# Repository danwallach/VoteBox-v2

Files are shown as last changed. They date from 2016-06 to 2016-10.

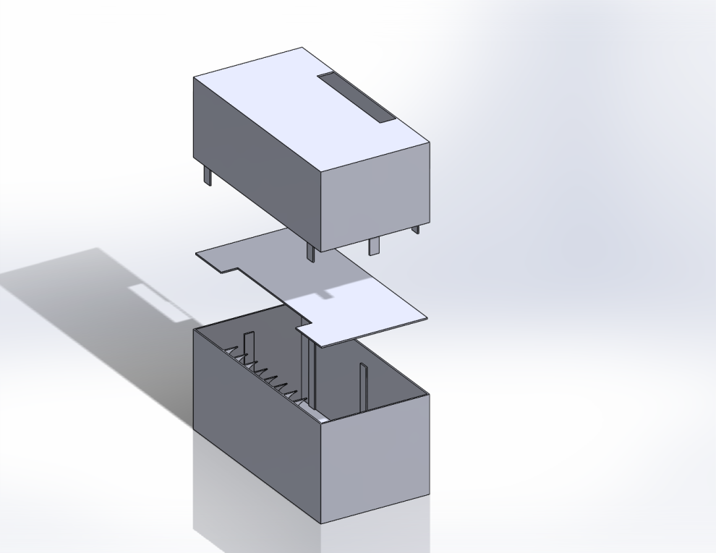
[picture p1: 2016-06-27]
box-schematics/box-render.png

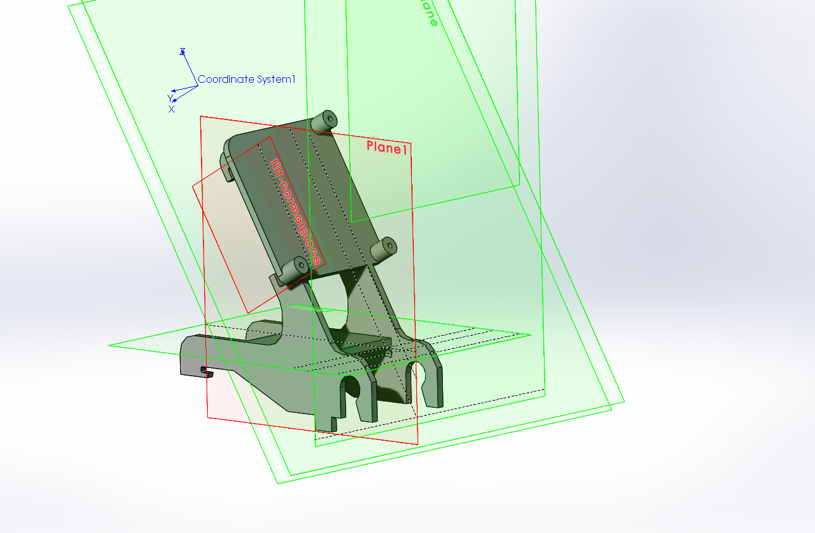
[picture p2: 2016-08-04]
box-schematics/holderbase.PNG

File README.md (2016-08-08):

# VoteBox version 2

An improved version of the original [Vote Box](https://github.com/danwallach/VoteBox-v1) created for the STAR-Vote project.

## Directories
*   `box-schematics` CAD schematics of mechanical components
*   `circuitdiagram` Electronic circuit diagrams
*	`java` Java ballotbox software implementation
*   `scan-src` Source files for barcode scanner module
*   `servo-src` Source files for hardware PWM servo module (experimental)

## Files
### Core Programs
*   `votebox.py` Main routine
*   `status_server.py` Ballot box status server for use with web frontend
*   `take_in.py` Paper intake and sorting routine
*   `diverter.py` Diverter control library
*   `rpi_servodriver.py` Servomotor control library
*   `scan` Barcode scanner program

### Configuration Files
*   `config.py` Config options for main program
*   `diverter_config.py` Config options for diverter controller

### Testing Programs
*   `servotest.py` Servomotor library test program
*   `servotest_interactive.py` Interactive servo test program

### Documentation
*   `network-notes.md` Documentation of Epson DS-510 driver hacking
*   `scanner-codes.md` Documentation of Epson ESCI/2 scanner communication protocol

### Miscellaneous
*   `ping_slack` Script that sends device IP to Slack chat

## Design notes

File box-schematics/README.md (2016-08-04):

# Solidworks schematics

## Barcode scanner mount
3D printed part that attaches the barcode scanner to the printer frame.

* `holderbase.sldprt` Solidworks part file.
* `holderbase.slddrw` Solidworks part drawing.
* `holderbase.stl` For 3D printer.

## Ballot box enclosure
Mockup of ballot box enclosure.

* `ballotbox-assy.sldasm` Solidworks file of assembled box.
* `ballotbox-bottompart.sldprt` Solidworks part file for base of box.
* `ballotbox-platepart.sldprt` Solidworks part file for printer support plate.
* `ballotbox-toppart.sldprt` Solidworks part file for top of box.
* `ballotbox-assy.pdf` Part drawing of assembled ballot box.
* `box-render.png` Render of assembled ballot box.

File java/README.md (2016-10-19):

# Ballot box driver, Java edition 1.9

Driver application for the STAR-Vote ballot box, written in Java for the Raspberry Pi.

## Requirements
- Raspberry Pi 3
- Java 1.8
- [WiringPi](http://wiringpi.com/)
- [Pi-blaster](https://github.com/sarfata/pi-blaster)

### Note on pi-blaster
Pi-blaster **must** be daemonized and configured with a pulse frequency of 50 Hz before
running this application (refer to its documentation to see how to do this). We have
also noted broken PWM behavior if the daemon is started immediately at boot. This was
resolved by delaying the start of pi-blaster by 30 seconds on boot.

*Update 9/28/2016*: The cause of the unreliable PWM behavior may be due to dynamic
PWM clock scaling specific to certain conditions on the Pi3 (possibly HDMI). To
resolve, run pi-blaster in PCM mode:

`./pi-blaster --pcm`

### Root access
The application may be run with normal privileges if the machine is running Raspbian
with Linux kernel version 4.1.7 or newer. Otherwise, the application must be run as
root to allow hardware GPIO access.

## Run
Run `./gradlew run. This should only be used for development testing.

## Install
To build the application locally:

`./gradlew installApp`

This will package the application and all dependencies into JARs and place
them in the directory `build/install/ballotbox`. Three variants of the
application are installed:

* `bin/ballotbox`: Networked to the STAR-Vote protocol and displays status
messages via a web-based UI. The UI itself must be downloaded and hosted
separately (see Votebox-Display).
* `bin/ballotboxsw`: Non-networked and displays status messages via Swing.
* `bin/ballotboxfx`: **Experimental.** Displays status messages via JavaFX.
Note that JavaFX is not included in the ARM JDK distribution, so this cannot
actually be run on the RPi.

**Important**: from the command line, the application must be started with
the working directory at the installation root. This is currently necessary
due to design flaws in legacy STAR-Vote code. For example, to start
`ballotboxsw`, use

~~~
cd build/install/ballotbox
bin/ballotboxsw
~~~

### Running from remote session
If running the Swing-based variant over SSH, the X11 display must be set to
the host's physical display. This can be done by setting the `DISPLAY`
environment variable:

`export DISPLAY=:0.0`

## Deploy
To package the application in a self-contained archive package:

`./gradlew distTar`

The resulting tar package is placed in `build/distributions`. This is the equivalent of
packaging the output of _Install_ in a tar archive.

## Documentation
Generate documentation by running

`./gradlew javadoc`

The resulting JavaDoc is placed under `build/docs`. Source code for this
project is formatted with Markdown and converted to JavaDoc HTML with the
[pegdown-doclet](https://github.com/Abnaxos/pegdown-doclet) plugin, which is
included in the provided Gradle configuration. The IntelliJ IDEA [Pegdown
Doclet plugin](https://plugins.jetbrains.com/plugin/7253?pr=idea) may be
optionally installed to properly render Markdown comments in the Quick
Documentation viewer.

## Source
This software was developed in IntelliJ IDEA and built with Gradle. Opening
this directory (`/java`) as project root in IntelliJ should import everything
in a working state. You may need to manually refresh Gradle for it to download
the necessary dependencies.

The Gradle task `application/run` can be used to run the program as configured
in Gradle. To run it through IntelliJ or manually, the main entry point is via
`edu.rice.starvote.Controller.main()`.

## Known Issues
* During operation, a `ConcurrentModificationException` is sometimes thrown.
This does not appear to interfere with any functionality. It is likely a bug
introduced in version 1.1 of the Pi4J library.

## Todo
- Debugging

## Authors
- luejerry

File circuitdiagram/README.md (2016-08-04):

# Ballot box electrical schema

## Folders
* `datasheets` Manufacturer datasheets for electronic components
* `PCB` Files for PCB fabrication
* `PCB-1.02` Files for PCB fabrication with onboard sound driver (has issues with interference noise, not suitable for use)

## Files 
* `rpi-ballotbox.fzz` [Fritzing](http://fritzing.org) circuit diagram file

### Circuit diagram
* `rpi-ballotbox_schem.svg` Render of circuit schematic
* `rpi-ballotbox_schem.png` Render of circuit schematic
* `rpi-ballotbox_schem.pdf` Render of circuit schematic

### Breadboard diagram
* `rpi-ballotbox_bb.png` Render of breadboard schematic
* `rpi-ballotbox_bb.svn` Render of breadboard schematic

### PCB diagram
* `rpi-ballotbox_pcb.pdf` Render of PCB schematic

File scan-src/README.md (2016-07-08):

# scan: barcode scanner program

## Compiling
Run `make`. The WiringPi library must be installed.

## Usage
Before running, ensure the barcode scanner is activated by HIGH signal on BCM
pin 25. Run `scan` as root.

* `sudo ./scan` Scan until valid code is read.
* `sudo ./scan 5` Scan until code read or 5 seconds have elapsed.

On successful code read, the program prints the code followed by a newline to
`stdout` and exits. Nothing is printed if no code is read.

## Notes
Only printable ASCII characters and the space character are supported. Should
be good for Code 128 and below.

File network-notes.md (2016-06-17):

# Compiling Epson scanner binaries for ARM

Epson does not provide precompiled ARM Linux driver binaries for the DS-510 scanner. It does, however, provide sources
available [here](http://support.epson.net/linux/src/scanner/imagescanv3/debian/imagescan_3.16.0.orig.tar.gz). We must
compile it ourselves to use the manufacturer drivers on the RPi.

## Compile epson imagescan (utsushi) drivers on the RPi

1. download and extract source tar:
    ```
    curl -LOC http://support.epson.net/linux/src/scanner/imagescanv3/debian/imagescan_3.16.0.orig.tar.gz
    tar -zxf imagescan_3.16.0.orig.tar.gz
    ```
    
2. install `libboost-dev-all`
3. run configure script, specifying boost library location (`/usr/lib/arm-linux-gnueabihf`)

    `./configure --with-boost-libdir=/usr/lib/arm-linux-gnueabihf`

4. `make`

This step failed with compiler error due to insufficient memory. Error persisted even after increasing swap space
to 8 GB. Cross compiling on a more powerful system appears to be necessary here.

## Cross-compiling utsushi drivers from amd64 Ubuntu 16.04 machine, take one

On target machine (rpi):

1. download boost c++ libraries

    `sudo apt-get install libboost-all-dev`

2. archive the installed binaries and transfer to build machine

    `tar -zcf lib.tar.gz /usr/lib/arm-linux-gnueabihf`

On build machine (amd64-ubuntu):

1. download and extract driver source as above
2. download c++ boost libraries

    `sudo apt-get install libboost-all-dev`

3. extract target boost binaries

    `tar -zxf lib.tar.gz`

4. download RPi cross compiling toolchain off github

    `git clone https://github.com/raspberrypi/tools`

5. add toolchain binaries for build system to PATH in ~/.bashrc

    `export PATH=$PATH:~/tools/arm-bcm2708/gcc-linaro-arm-linux-gnueabihf-raspbian-x64/bin`

6. run configure script, specifying target boost library location and cross-compile host

    `./configure --with-boost-libdir=./lib/arm-linux-gnueabihf --build=x86_64-linux-gnu --host=arm-linux-gnueabihf`

7. `make`

8. archive the directory and transfer to target machine

On target machine:

1. reconfigure to target

    `./configure --with-boost-libdir=/usr/lib/arm-linux-gnueabihf`

2. `make check`

   * This step failed with binaries in utsushi/connexions/.lib failing tests. Easy solution is to just recompile these
natively, since these are not a problem for the pi
    ```
    cd connexions
    make
    ```

   * Rerun `make check` in project root 

   * Now errors are generated due to missing dependencies used by the testsuite. Install them

    `apt-get install tesseract-ocr graphicsmagick doxygen graphviz`

   * The Makefile in `./filters/tests` needs to be updated to point to graphicsmagick. Do not rerun configure; it will
force a recompile. Change the `CONVERT=` to

    `CONVERT=gm convert`

   * Rerun `make check`

At this point, it became evident that make had used the built-in gcc rather than the cross-compiler, possibly due to
autodetection of x86\_64 libraries. I decided to abandon the cross-compiling approach and go with full environment
emulation instead, since the road of cross-compiling the entire dependency tree leads only to horrors beyond mortal
comprehension.

## Compiling utsushi drivers with ScratchBox2 and qEmu

Fortunately, another brave soul had set up a VM for emulated compilation with ScratchBox2 and qEmu and posted it to
[Github](https://github.com/nickhutchinson/raspberry-devbox). Unfortunately, it was quite outdated, using the previous
distribution of Raspbian (Wheezy) and an old cross compilation toolchain. Trying to compile the drivers in emulation
mode was met with many errors and warnings of deprecated assembly output (?!). After an afternoon of modifications to
the VM provisioning scripts, I was able to generate a VM using the current Raspbian Jessie distribution and cross
compilation toolchain, which I have placed in [this Github repository](https://github.com/luejerry/raspberry-devbox).

The emulated compilation approach uses ScratchBox2 and qEmu to emulate a Raspbian chroot, itself inside an Ubuntu 12
VM running in Vagrant/Virtualbox on the host system. Fully emulated compilation is extremely slow, a small price to
pay for one's sanity.

On host machine (amd64 ubuntu):

1. Get the scratchbox2/qemu RPi VM box

    `git clone https://github.com/luejerry/raspberry-devbox`

2. Set it up using the instructions in README
    ```
    vagrant up
    vagrant ssh
    ```

3. At this stage, a problem with mismatching locales was encountered ("could not set locale"). To fix, generate locales
for all en\_US languages

    `sb2 -eR dpkg-reconfigure locales`

   * Select (spacebar) all locales starting with `en_US`
   * Choose `en_US` as default locale

4. Download and extract driver source as above
5. Download boost libraries to the chroot

    `sb2 -eR apt-get install libboost-all-dev`

6. Run configure in emulation mode, specifying a staging directory

    `sb2 -e ./configure --with-boost-libdir=/usr/lib/arm-linux-gnueabihf --prefix=$HOME/deploy`

7. Run make in emulation mode (takes a long time)

    `sb2 -e make`

8. Run make check in emulation mode

    `sb2 -e make check`

   * Could not get past this point on the host machine due to test programs segfaulting when running under qEmu. Since
the hard part has been built, we can copy the build products to the Pi and run the test there, being careful not to
trigger a recompile

9. Archive the utsushi folder and send to Pi

On target machine (arm rpi):

1. Extract the utsushi folder to the same absolute path as on host, or symlink to it

    `sudo ln -s /home/pi /home/vagrant`

2. Install the necessary dependencies in `install-deps.sh` (we installed by hand to avoid installing unnecessary automake
tools)

    `sudo ./install-deps.sh`

3. `make check`

4. `sudo make install`

   * This will install to the prefix folder specified when configure was ran, in this case `~/deploy`. A driver file is
also installed to `/etc/udev/rules.d`.

# Compiling SANE binaries for ARM

[SANE](www.sane-project.org) introduced partial support for the DS-510 in version 1.0.25 with the introduction of the
`epsonds` module. Although the SANE frontend can be used with Utsushi, the backend driver is completely independent and
gives us an alternative option for using the scanner on the Pi.

## Precompiled binaries

The latest precompiled SANE packages on the Raspbian Jessie repository are version 1.0.24, which is outdated and does not
support the DS-510. We tried installing the latest stable release (1.0.25) from the experimental Debian Stretch repository,
but encountered a known bug in which the scanner would only accept one command successfully before failing with an IO error.
Others had reported this bug fixed in the latest unstable snapshots, which are only available as source and thus have to be
compiled. Fortunately, the RPi 3 is more than capable of compiling the necessary modules natively without the need for any
cross compilation insanity.

## Compiling on RPi

### Compiling backend driver

The backend driver module `epsonds` must be compiled and installed before the frontend is installed.

1. Download the SANE development sources from Github.

    `git clone git://git.debian.org/sane/sane-backends.git`

   - We received `sane-backends` on commit `e7100e275d58d67b903e883e7a02e45d18f81ef7`.

2. Make sure `libusb-dev` is installed.

3. Run configure in `sane-backends`, specifying that only to compile the driver module we need

    `./configure BACKENDS="epsonds"`

4. `make`

5. `sudo make install`

### Compiling frontend driver

1. Download the SANE development sources from Github.

    `git clone git://git.debian.org/sane/sane-frontends.git`

2. `./configure`

3. `make`

4. `make install`

5. Add `/usr/local/lib` to the library search path by adding it to `ld.so.conf` and running `ldconfig` as root. Alternatively,
set the environment variable `LD_LIBRARY_PATH=/usr/local/lib` in execution

    `LD_LIBRARY_PATH=/usr/local/lib scanimage -L`

# Useful tricks

- To see exactly which libraries are being loaded (and which ones are failing to load), set the environment variable `LD_DEBUG`:
    ```
    export LD_DEBUG=files	# displays library files
    export LD_DEBUG=bindings	# displays symbol bindings
    export LD_DEBUG=libs	# displays lib search paths
    export LD_DEBUG=help	# displays other possible options
    ```

- To write both stdout and stderr to a file while still printing to the console, use

    `<command> 2>&1 | tee <outfile>`

# Temporary notes

- _Make sure `pkg-config` is installed in the RPi chroot!_ It comes installed on the normal Raspbian distro but not when
using `debootstrap`. Epson driver `configure` will silently fail to detect `libudev` and `libusb` if this is not installed!

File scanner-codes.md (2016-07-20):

# Scanner code documentation
Scanner request/responses are encoded in 64-byte string tokens beginning with a
four character code. All available codes are provided in the `utsushi` source
file `utsushi/drivers/esci/code-token.hpp` but their meaning appears to be
undocumented. This is a list of tokens with their inferred meanings from
examining the source code.

Tokens are grouped into namespaces (sections) in the source according to their
general function. The grouping has been preserved here.

## Request tokens

| Token | Definition |
| ----- | --- |
| FIN | Finished with device |
| CAN | Cancel command |
| INFO  | Get scanner information |
| CAPA  | Get scanner capabilities |
| CAPB  | Get scanner capabilities, flip side only |
| PARA  | Get/set parameters |
| PARB  | Get/set parameters, flip side only |
| RESA  | Get/set resolution |
| RESB  | Get/set resolution, flip side only |
| STAT  | Get scanner status |
| MECH  | Send mechanical command (below) |
| TRDT  | Initiate scan, transition to data state (below) |
| IMG | Acquire scanned image data |
| EXT0  | Transfer blobs |
| EXT1  | Transfer blobs |
| EXT2  | Transfer blobs |

## Response tokens

### Request Error
All responses are headed by the original request code received, unless an error
occurs: a `UNKN` response indicates an unknown request code, and `INVD`
indicates that a known request was received at an invalid time.

### Info

#### Types
Each token here may be followed by additional tokens specific to its type,
defined in another section below. 

| Token | Definition |
| ----- | --- |
| #ERR  | Hardware error |
| #NRD  | Not ready |
| #PST  | Page start, sent after first IMG request for an image |
| #PEN  | Page end, sent after image completes scanning |
| #LFT  | Images left to scan, if number of pages was specified using PAG |
| #TYP  | Side of page being scanned |
| #ATN  | Device attention |
| #PAR  | Scan parameter notification, in response to PARA, PARB, RESA, OR RESB request |
| #END  | End of response, is not necessarily present |

#### ERR tokens
Hardware location of error:

| Token | Definition |
| ----- | --- |
| ADF | Automatic document feeder |
| TPU | Transparency unit |
| FB | Flatbed |

Nature of error:

| Token | Definition |
| ----- | --- |
| OPN | |
| PJ | Paper jam |
| PE | |
| ERR | Generic error |
| LOCK  | |
| DFED  | |
| DTCL  | |
| AUTH  | |
| PERM  | |
| BTLO  | |

#### NRD tokens

| Token | Definition |
| ----- | --- |
| RSVD  | |
| BUSY  | Device busy |
| WUP | |
| NONE  | |

#### TYP tokens

| Token | Definition |
| ----- | --- |
| IMGA  | Front side |
| IMGB  | Back side |

#### ATN tokens

| Token | Definition |
| ----- | --- |
| CAN | |
| NONE  | |

#### PAR tokens

| Token | Definition |
| ----- | --- |
| OK | Parameters set successfully |
| FAIL  | Failed to set parameters |
| LOST  | |

## Value tokens

| Token | Definition |
| ----- | --- |
| LIST  | List of integers or tokens |
| RANG  | Range defined by two integers |

## Capability tokens
Todo

## Parameter tokens
Truncated

| Token | Definition |
| ----- | --- |
| #PAG  | Number of images to scan. Each duplex scan counts as two images |

## Mechanical tokens
Type of mechanical action:

| Token | Definition |
| ----- | --- |
| #ADF  | Automatic document feeder |
| #FCS  | Focus control |
| #INI  | |

ADF actions:

| Token | Definition |
| ----- | --- |
| LOAD  | Load sheet |
| EJCT  | Eject sheet |
| CLEN  | Clean |
| CALB  | Calibrate |

FCS actions:

| Token | Definition |
| ----- | --- |
| AUTO  | Autofocus |
| MANU  | Manual focus |

## Transition (TRDT)
The `TRDT` request initiates the scan, putting the scanner in "data state."
Only `FIN`, `CAN`, `IMG` and `EXT` requests can be sent in this state. The
scanner exits this state when images have been acquired, it receives a `FIN`
or `CAN` request, or an error occurs. When not in this state, `CAN` and `IMG`
requests are considered invalid.

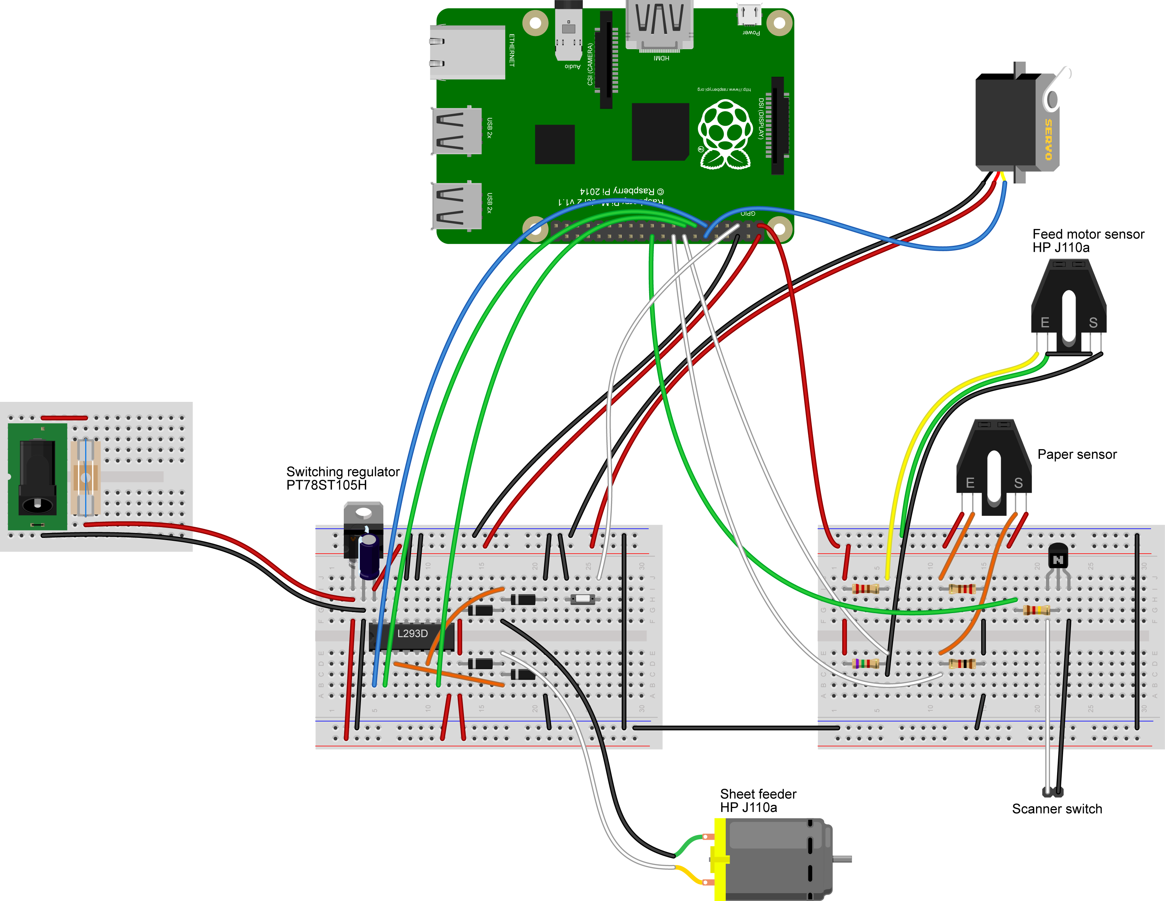
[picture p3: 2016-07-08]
circuitdiagram/rpi-ballotbox_bb.png

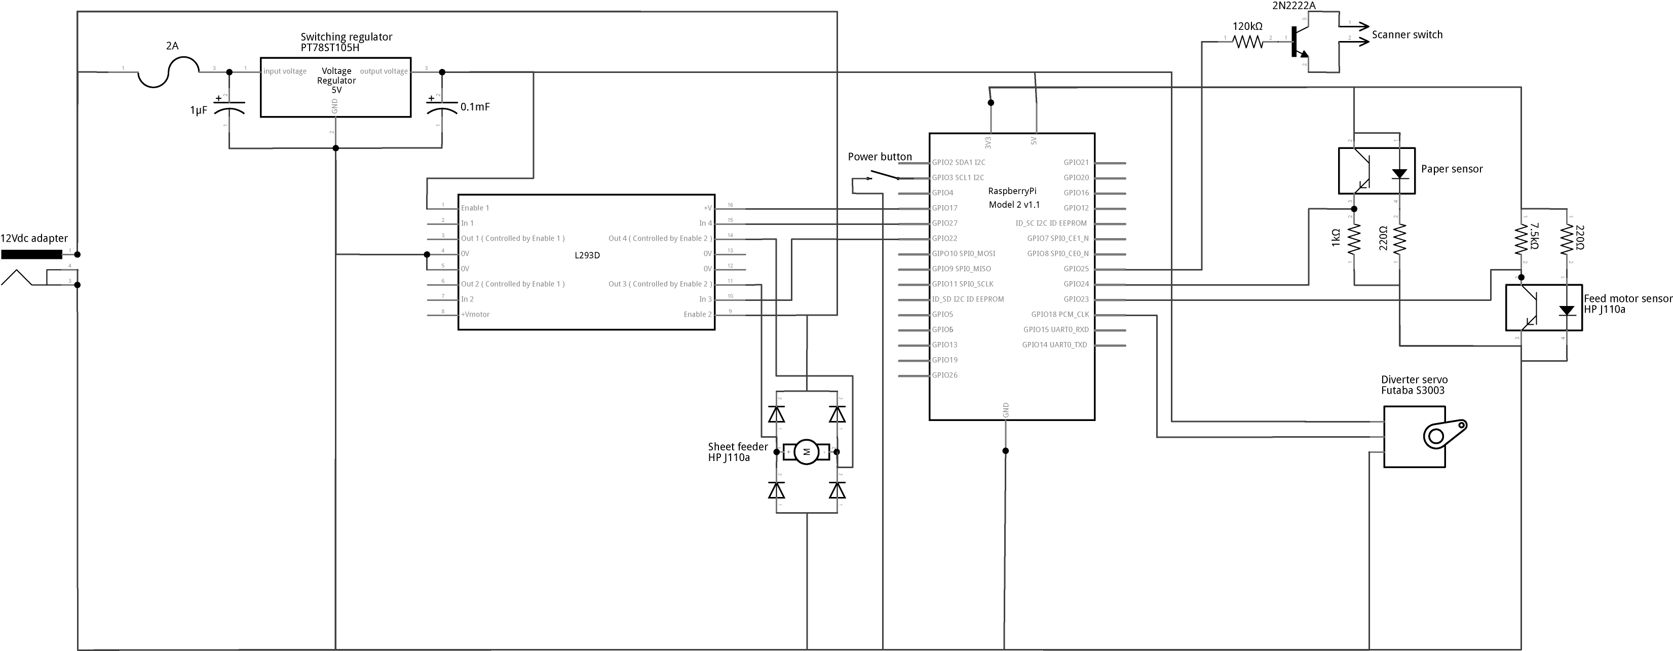
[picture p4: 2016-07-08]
circuitdiagram/rpi-ballotbox_schem.png

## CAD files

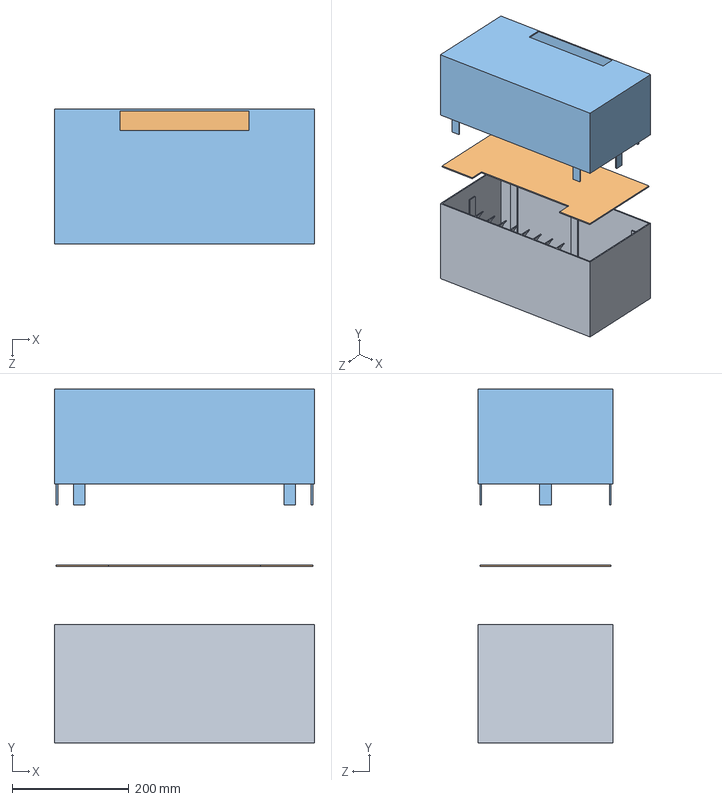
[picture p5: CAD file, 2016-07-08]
box-schematics/ballotbox-assy.SLDASM
446.0 x 606.3 x 231.0 mm
ballotbox-bottompart
ballotbox-platepart
ballotbox-toppart

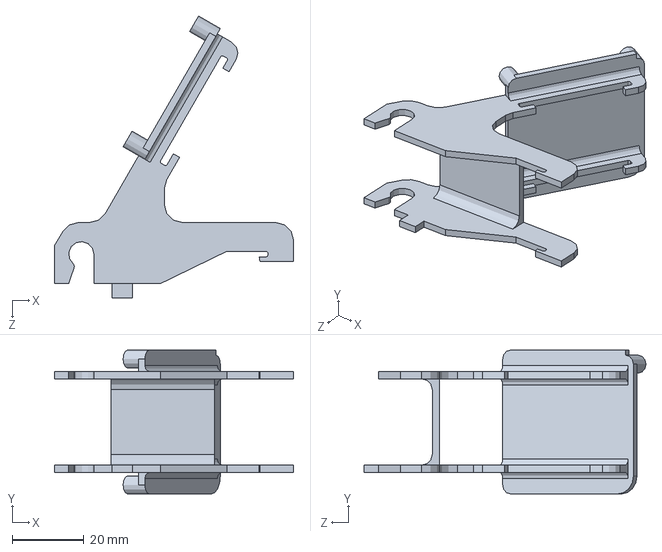
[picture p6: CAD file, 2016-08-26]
box-schematics/holderbase.SLDPRT
66.6 x 40.0 x 78.5 mm

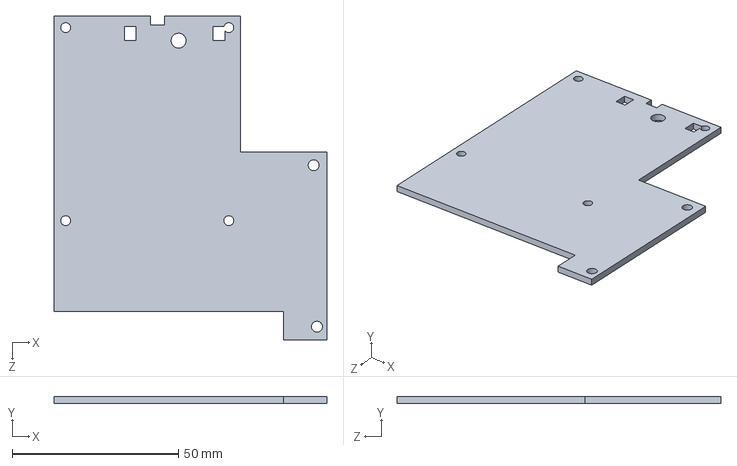
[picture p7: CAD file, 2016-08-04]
circuitdiagram/rpimount.SLDPRT
82.0 x 2.10 x 97.3 mm

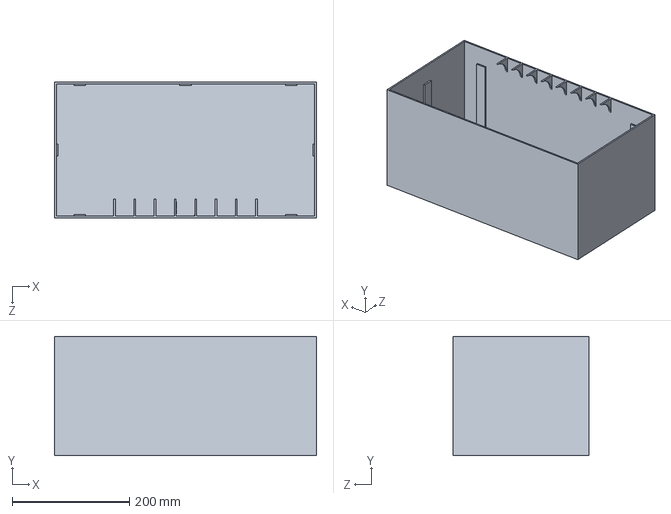
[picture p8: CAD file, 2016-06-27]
box-schematics/ballotbox-bottompart.sldprt
446.0 x 203.0 x 231.0 mm

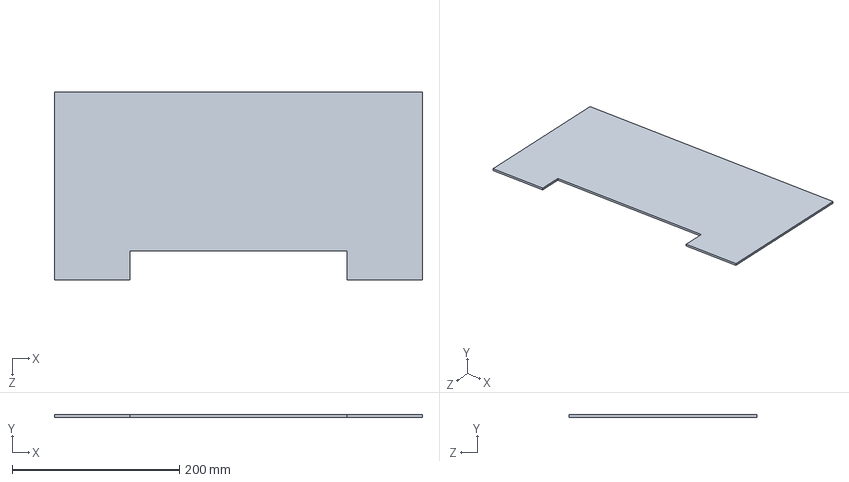
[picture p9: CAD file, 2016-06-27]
box-schematics/ballotbox-platepart.sldprt
440.0 x 3.00 x 225.0 mm

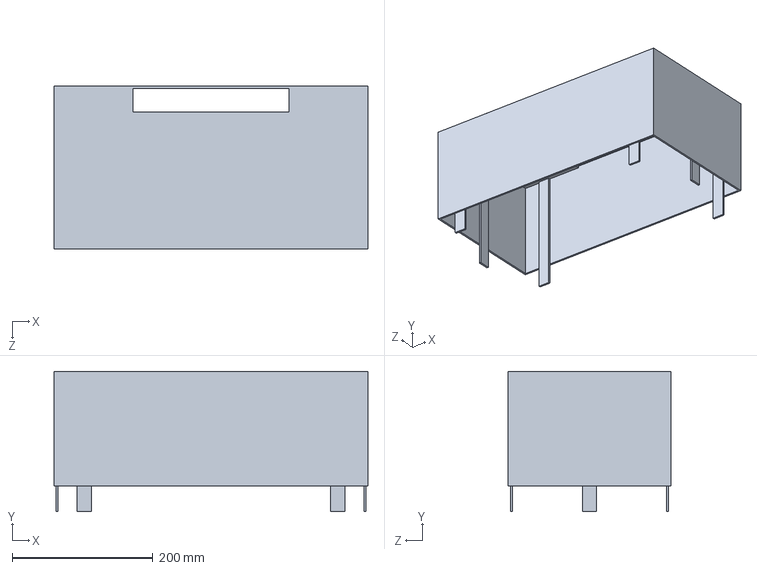
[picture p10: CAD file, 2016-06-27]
box-schematics/ballotbox-toppart.sldprt
446.0 x 199.0 x 231.0 mm

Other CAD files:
box-schematics/ballotbox-assy.SLDDRW
box-schematics/holderbase.SLDDRW
box-schematics/holderbase.STL
circuitdiagram/rpimount.DXF
circuitdiagram/rpimount.SLDDRW

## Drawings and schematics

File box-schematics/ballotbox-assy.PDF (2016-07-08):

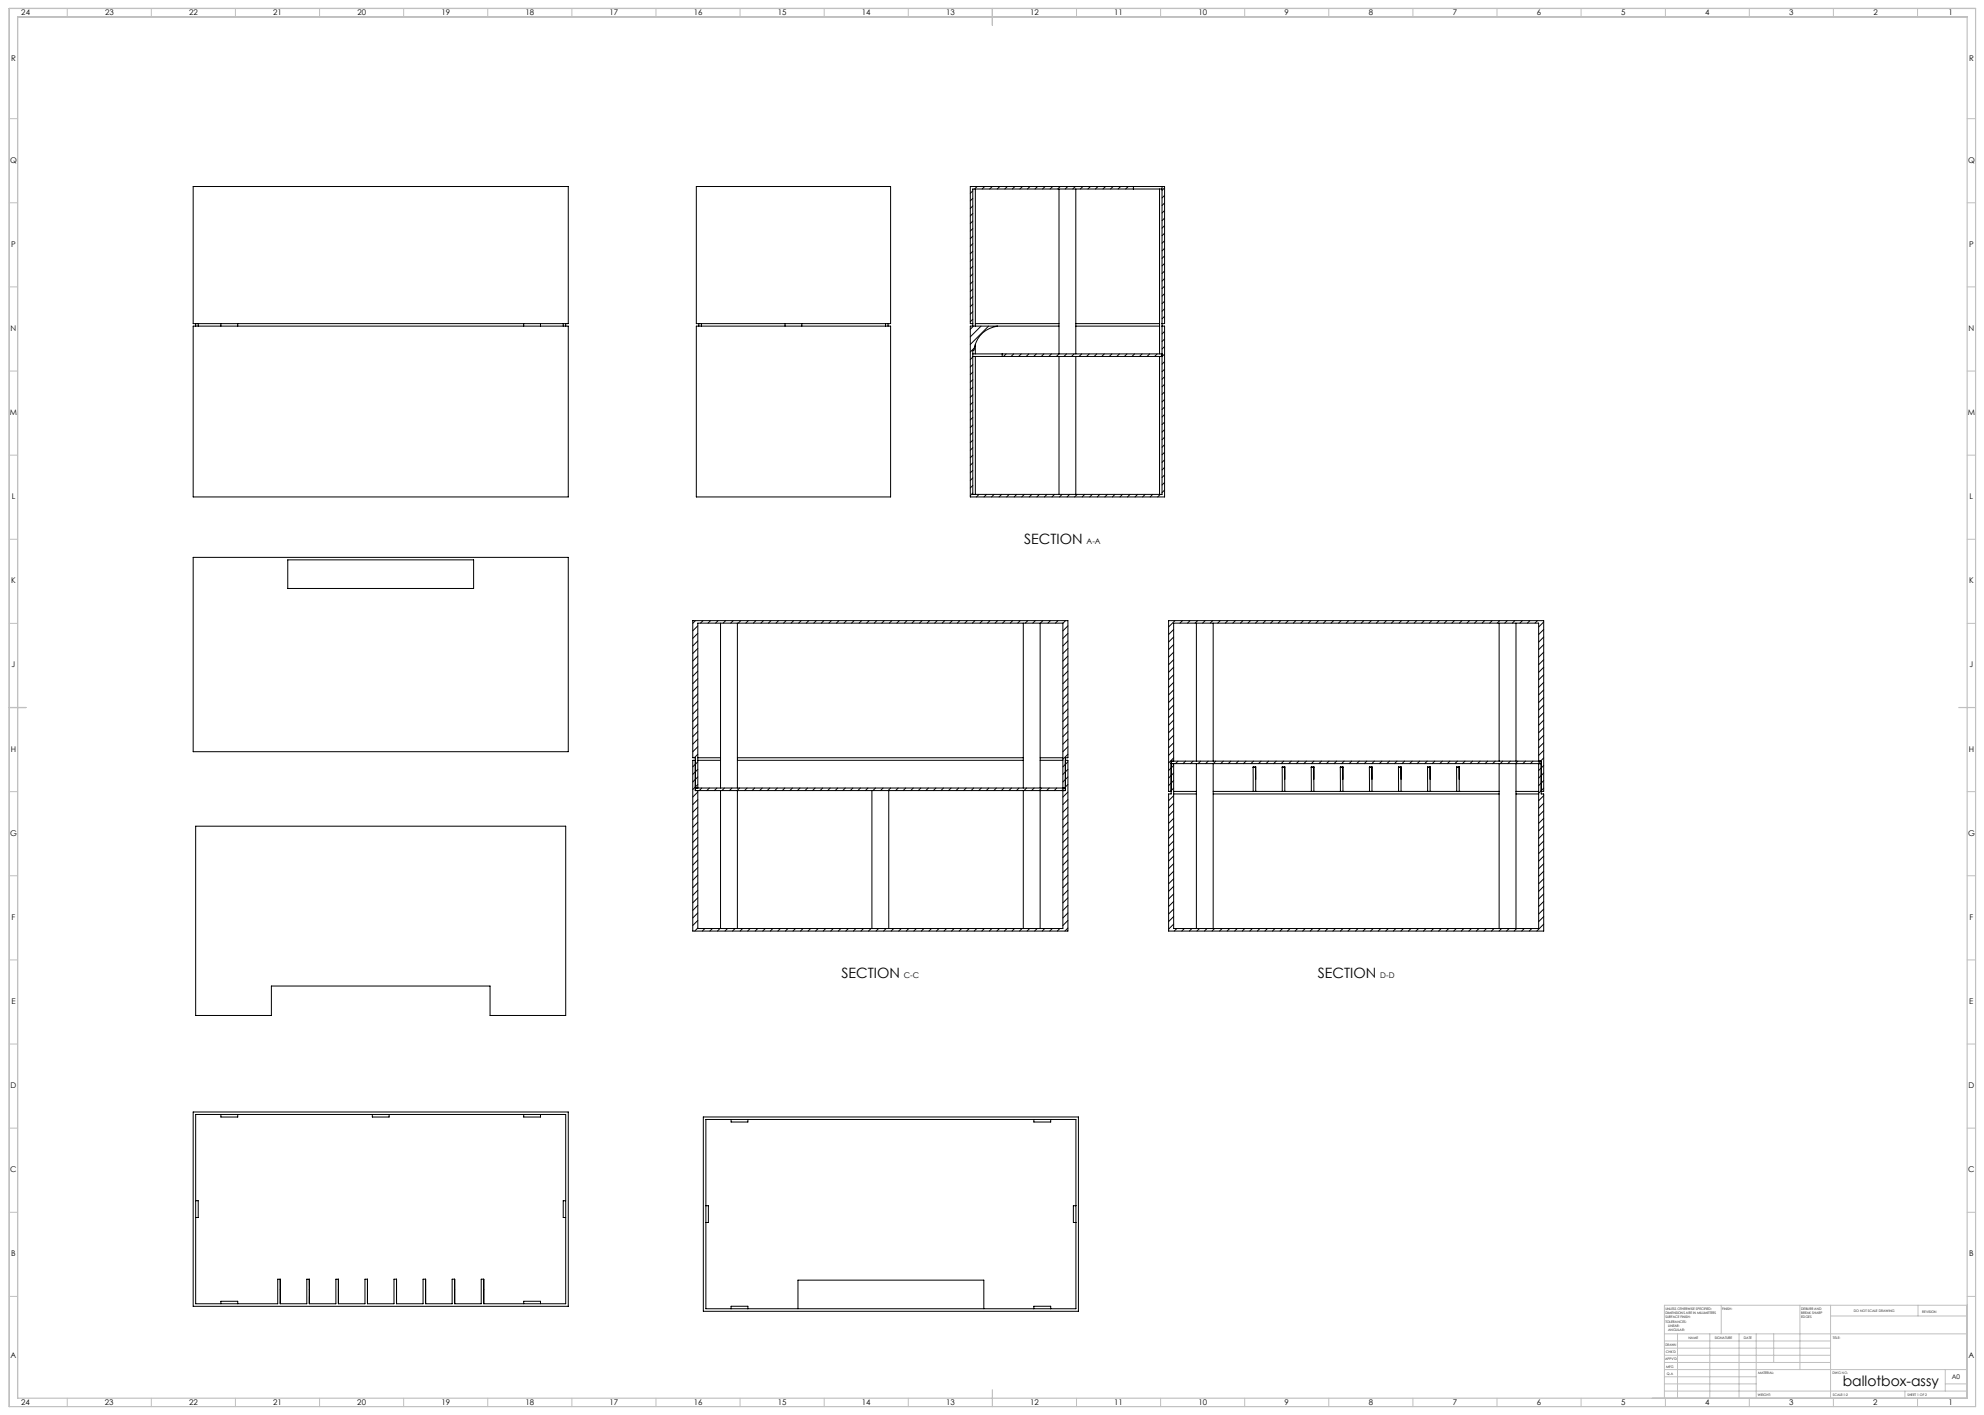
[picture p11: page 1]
SECTION A-A; SECTION C-C; SECTION D-D; FINISH:; DEBURR AND; BREAK SHARP; DO NOT SCALE DRAWING; REVISION; SCALE:1:2; SHEET 1 OF 2

UNLESS OTHERWISE SPECIFIED:
DIMENSIONS ARE IN MILLIMETERS
SURFACE FINISH:
TOLERANCES:
LINEAR:
ANGULAR:

NAME | SIGNATURE | DATE | | | | TITLE:

DRAWN
CHK'D
APPV'D
MFG
Q.A | | | | MATERIAL: | DWG NO. ballotbox-assy | A0

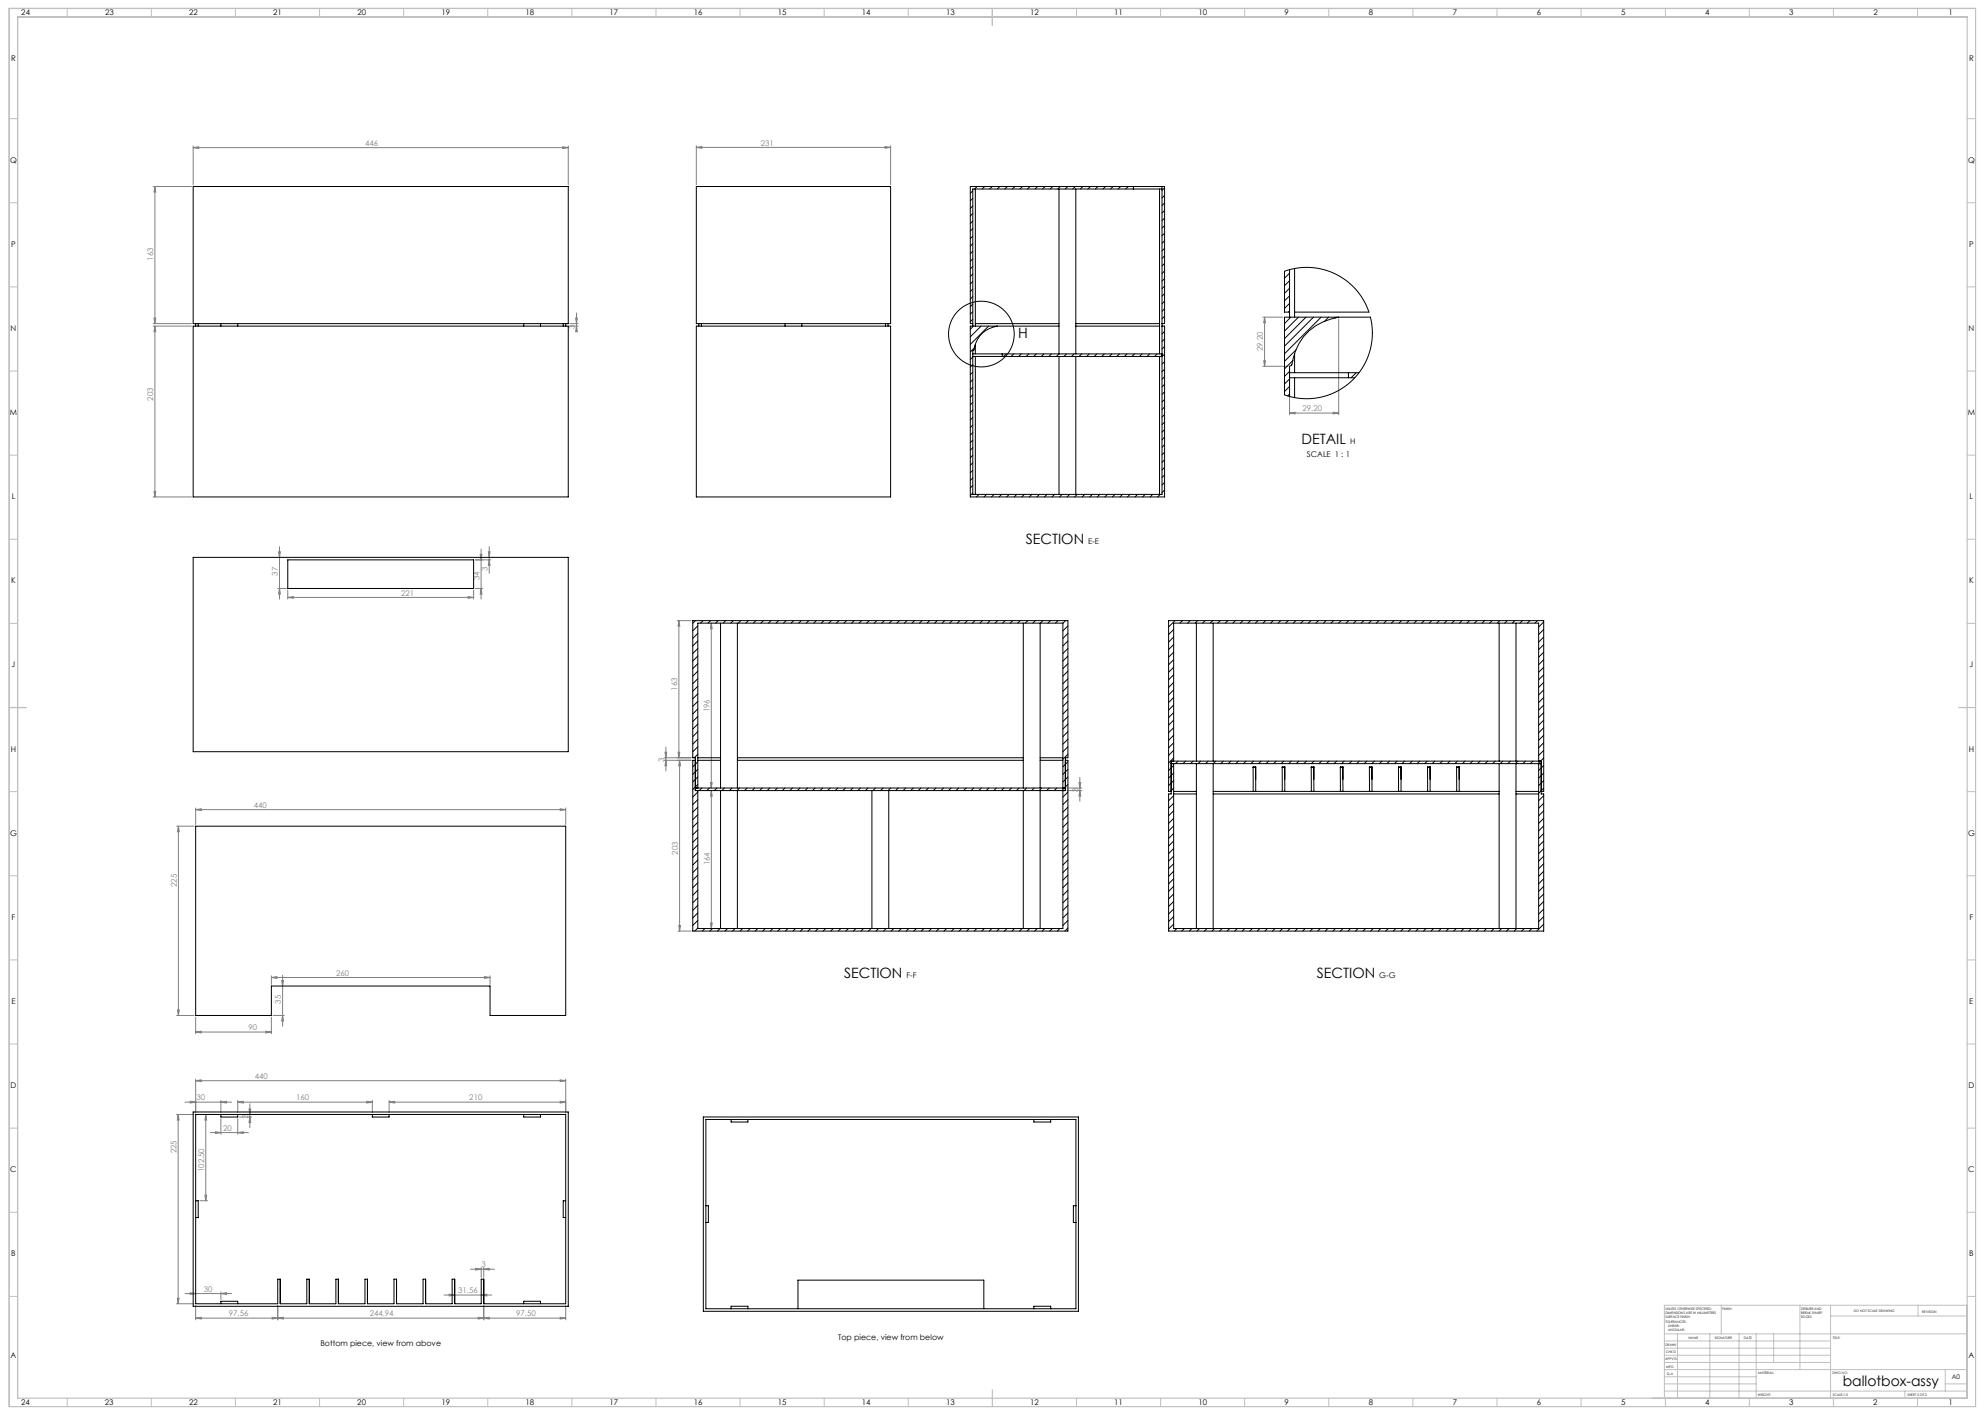
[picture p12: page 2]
SECTION E-E; Bottom piece, view from above; Top piece, view from below 203; SECTION F-F; SECTION G-G 29.20; DETAIL H; SCALE 1 : 1; FINISH:; DEBURR AND; BREAK SHARP; DO NOT SCALE DRAWING; REVISION; SCALE:1:2; SHEET 2 OF 2

UNLESS OTHERWISE SPECIFIED:
DIMENSIONS ARE IN MILLIMETERS
SURFACE FINISH:
TOLERANCES:
LINEAR:
ANGULAR:

NAME | SIGNATURE | DATE | | | | TITLE:

DRAWN
CHK'D
APPV'D
MFG
Q.A | | | | MATERIAL: | DWG NO. ballotbox-assy | A0

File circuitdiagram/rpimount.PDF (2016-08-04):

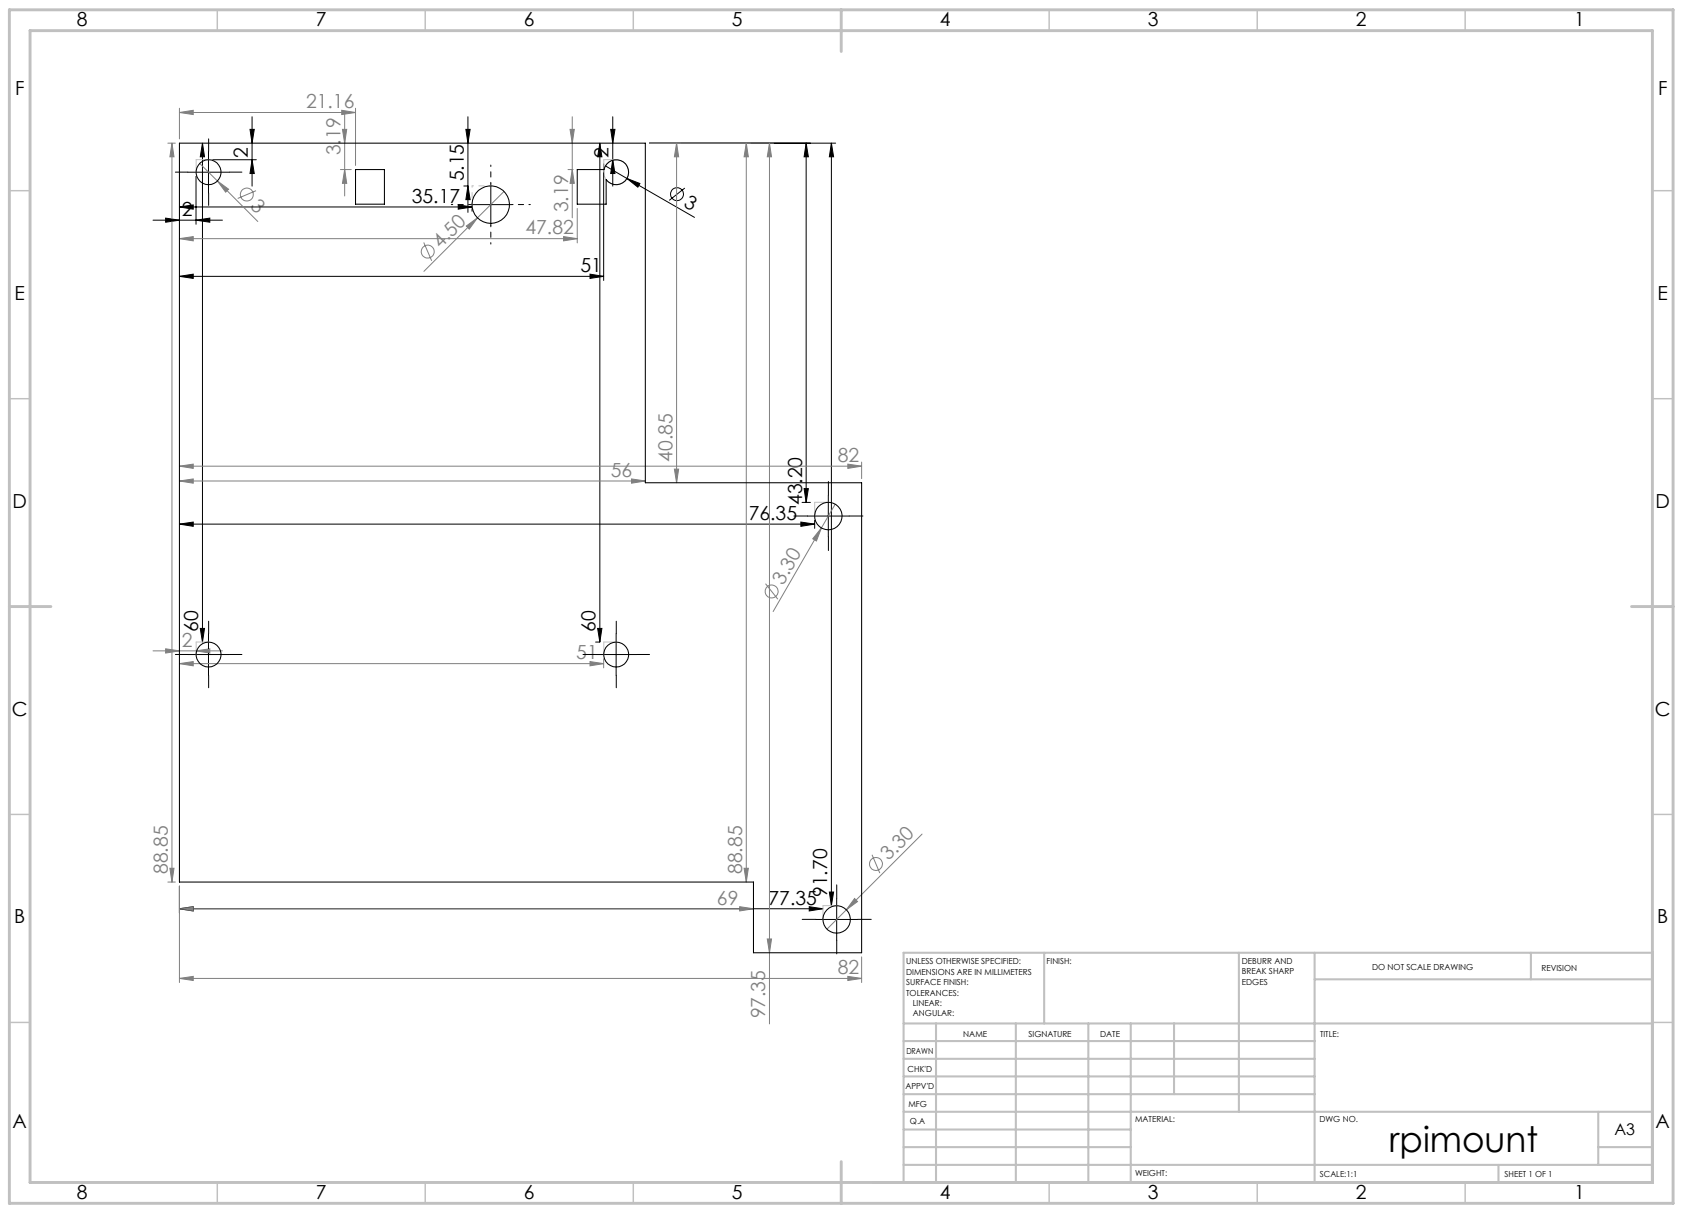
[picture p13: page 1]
FINISH:; DEBURR AND; BREAK SHARP; DO NOT SCALE DRAWING; REVISION; SCALE:1:1; SHEET 1 OF 1

UNLESS OTHERWISE SPECIFIED:
DIMENSIONS ARE IN MILLIMETERS
SURFACE FINISH:
TOLERANCES:
LINEAR:
ANGULAR:

NAME | SIGNATURE | DATE | | | | TITLE:

DRAWN
CHK'D
APPV'D
MFG
Q.A | | | | MATERIAL: | DWG NO. rpimount | A3

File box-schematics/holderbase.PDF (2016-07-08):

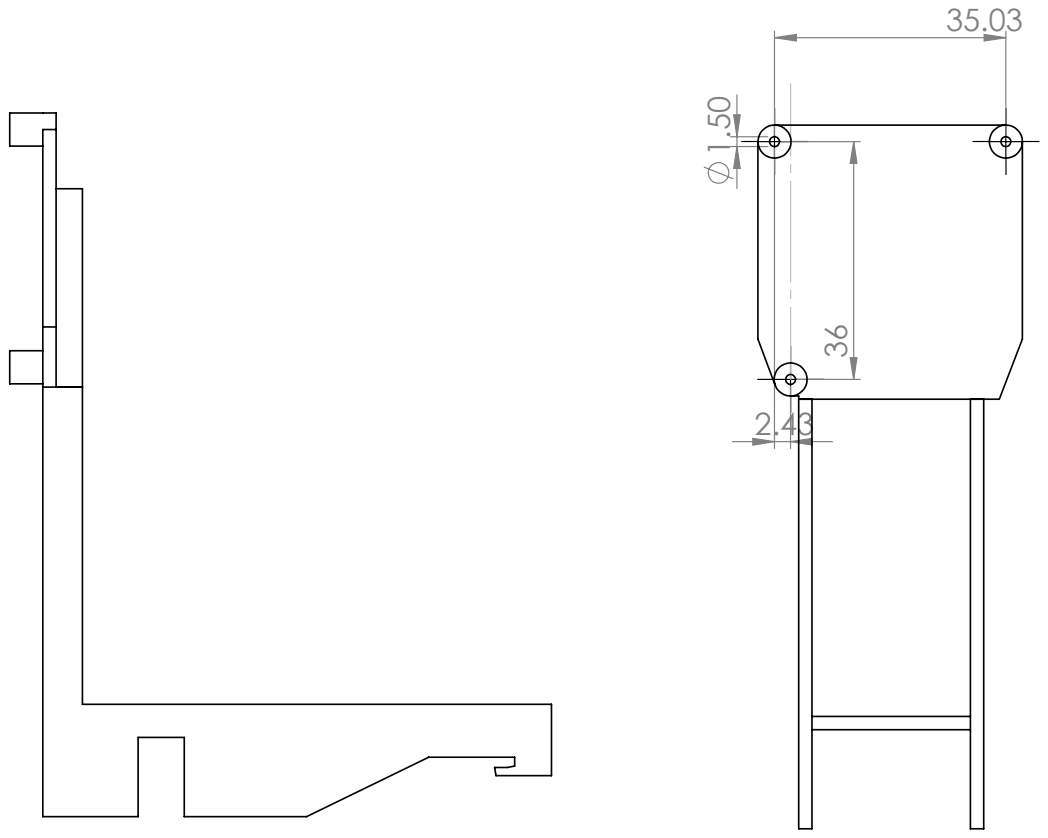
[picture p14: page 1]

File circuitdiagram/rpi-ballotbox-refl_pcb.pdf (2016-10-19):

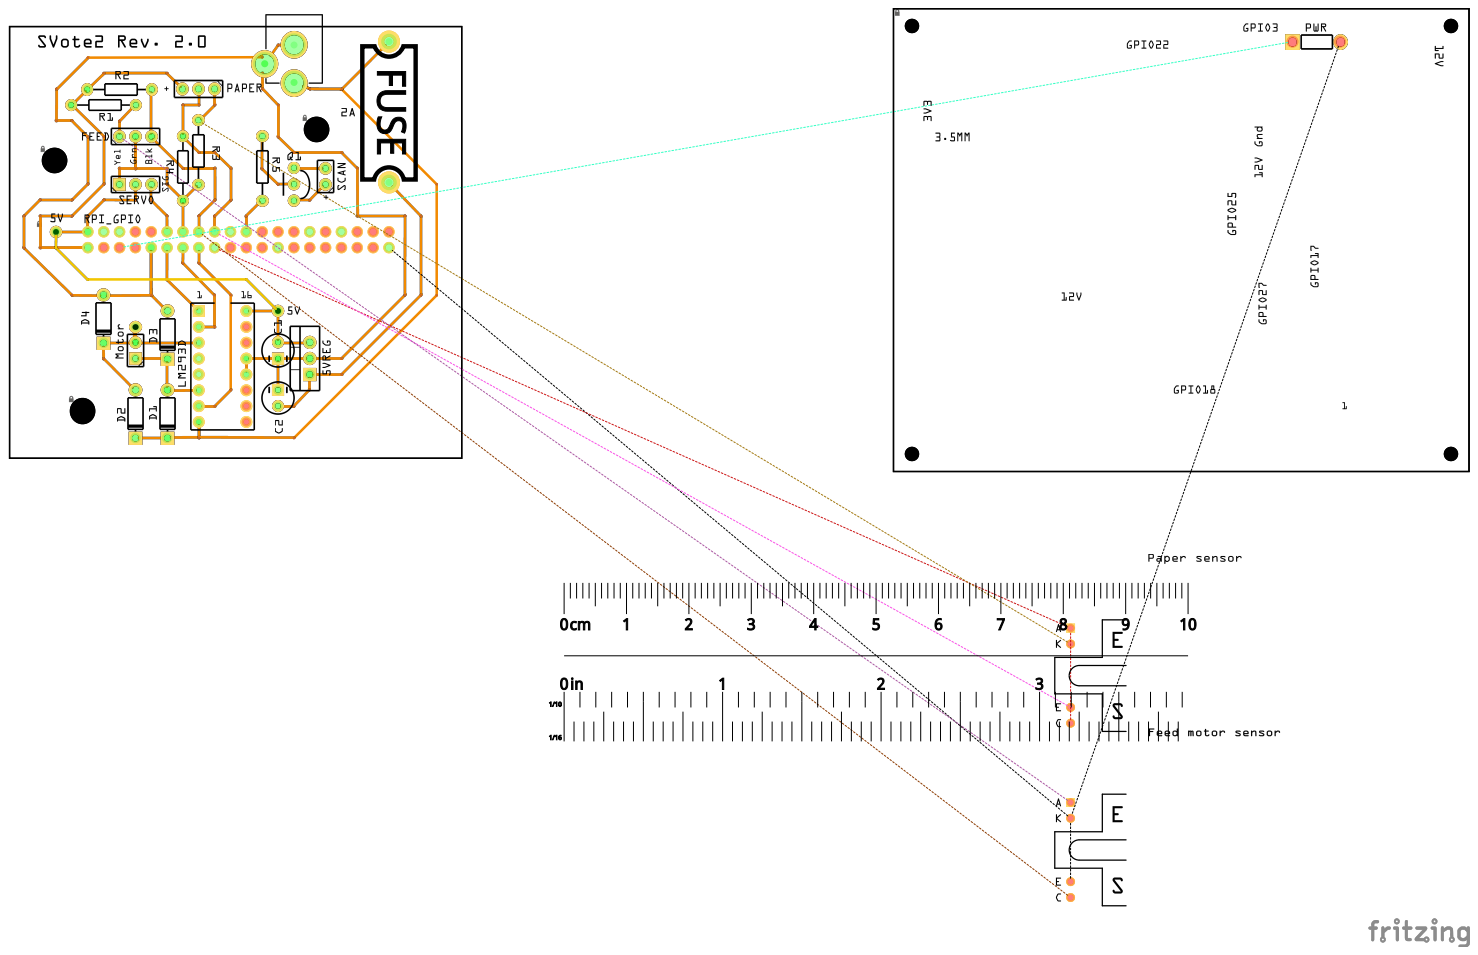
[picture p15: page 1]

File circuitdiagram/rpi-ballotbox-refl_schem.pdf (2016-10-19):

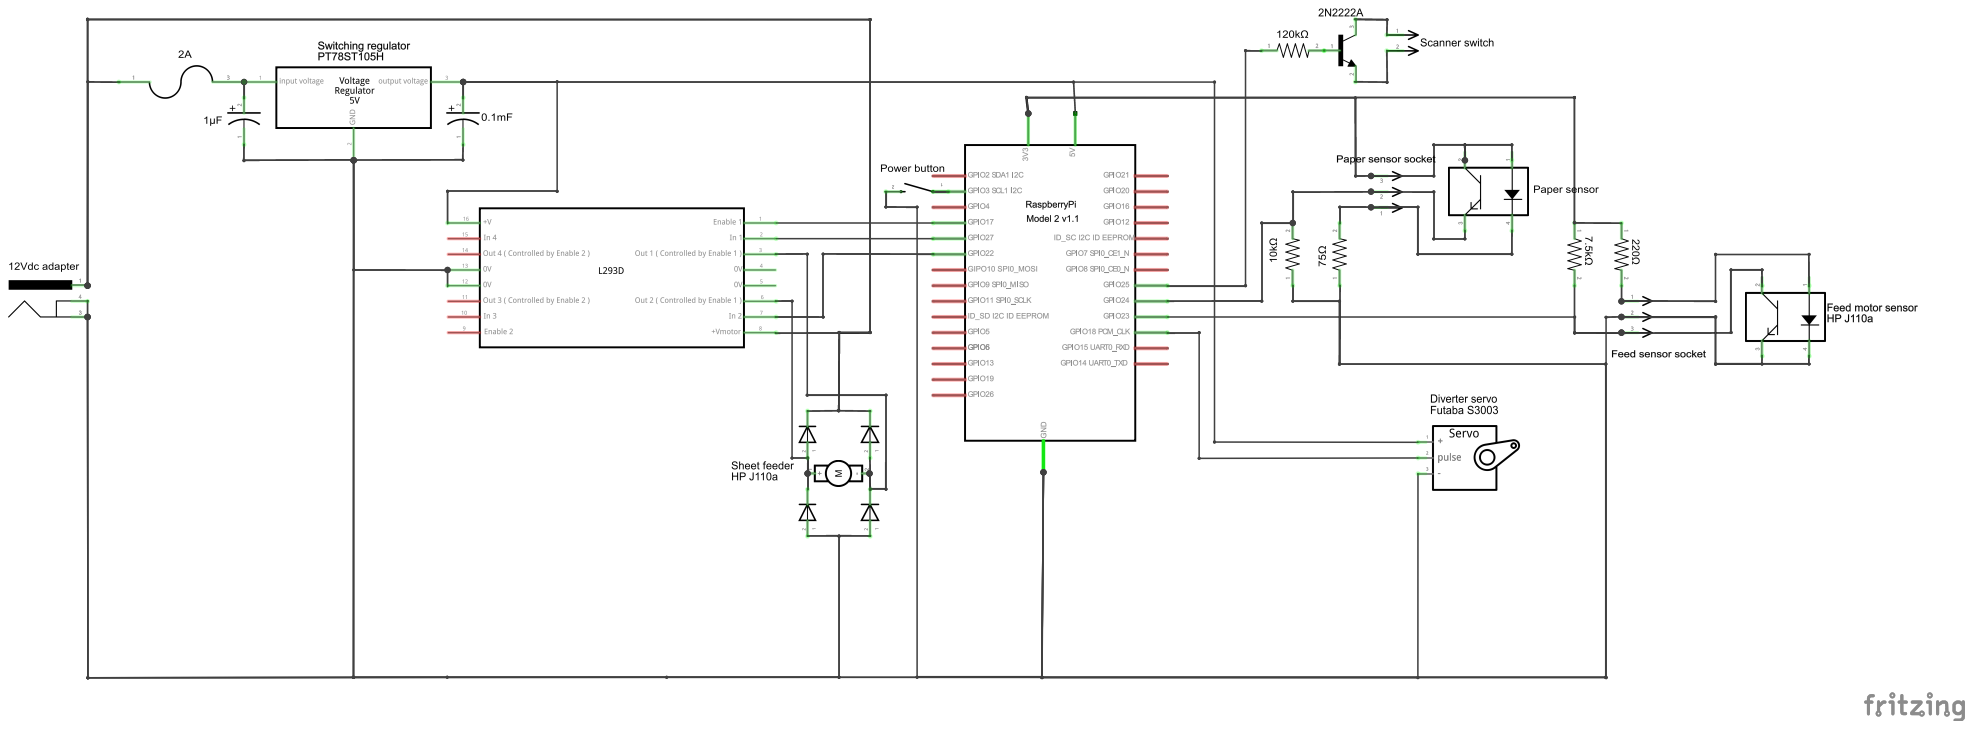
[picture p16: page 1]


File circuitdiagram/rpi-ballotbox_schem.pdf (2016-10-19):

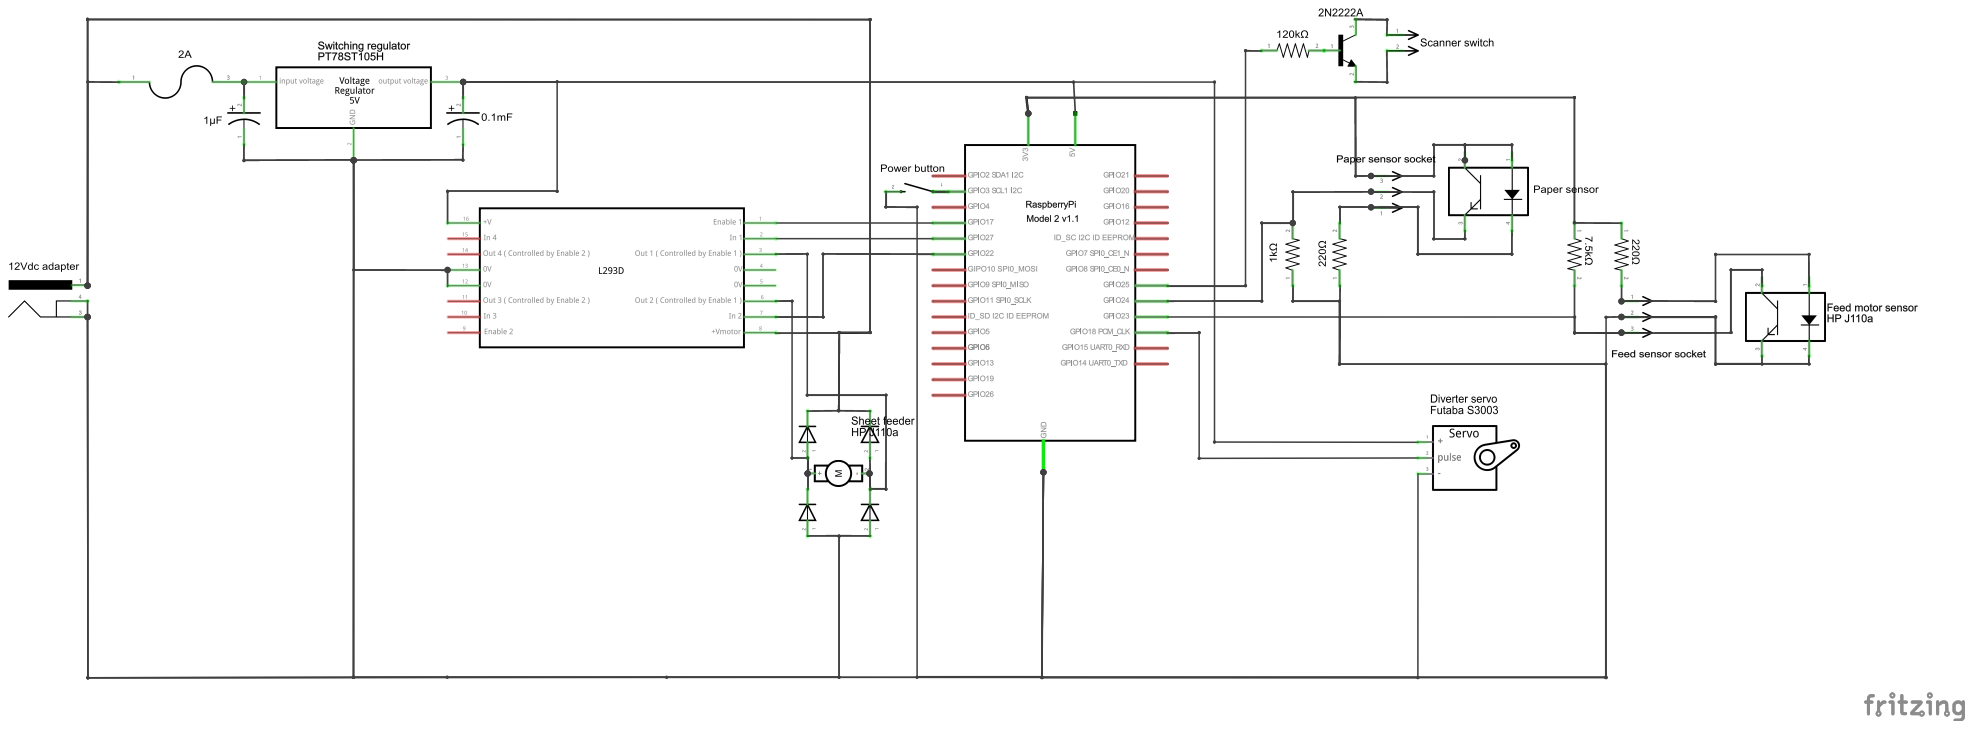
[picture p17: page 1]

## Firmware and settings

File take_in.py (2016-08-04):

#!/usr/bin/env python

import RPi.GPIO as GPIO
import time
import logging
import subprocess

# To relaunch script as sudo.
# See https://gist.github.com/davejamesmiller/1965559
import os
import sys

import config
import diverter

"""
Takes in all ballots placed in tray. 

Driven by the paper feeder of the HP Deskjet 1000 J110.
"""
logging.basicConfig(level=logging.DEBUG)

# Output pins.
MOTOR_ENABLE = 17
MOTOR_FORWARD = 22
MOTOR_BACKWARD = 27

# Input pins.
HALFWAY_TRIGGER = 23

def setup():
    """Set up the GPIO pins as input and output."""
    logging.info("Running Ballot Diverter V2.")

    logging.info("Setting up pins...")

    GPIO.setmode(GPIO.BCM)

    GPIO.setup(MOTOR_ENABLE, GPIO.OUT)
    pwm = GPIO.PWM(MOTOR_ENABLE, 50)
    pwm.start(0)

    GPIO.setup(MOTOR_FORWARD, GPIO.OUT)
    GPIO.setup(MOTOR_BACKWARD, GPIO.OUT)

    GPIO.setup(HALFWAY_TRIGGER, GPIO.IN, pull_up_down=GPIO.PUD_UP)

    logging.info("Brocasting status - 'Waiting.'")
    config.status = "waiting"

    return pwm

def take_in(pwm):
    """Take in all ballots."""
    tray_empty = False
    diverter.up()
    timeout = time.time() + 1   # One second from now.

    logging.info("Taking in a sheet...")

    logging.info("Broacasting status - 'Pending.'")
    config.status = "pending"

    logging.debug("Rolling forward...")
    before_halfway = GPIO.input(HALFWAY_TRIGGER) # True if trigger depressed.
    while before_halfway:
        pwm.ChangeDutyCycle(100)
        GPIO.output(MOTOR_FORWARD, True)
        GPIO.output(MOTOR_BACKWARD, False)

        if time.time() > timeout:
            logging.info("Tray is empty.")
            tray_empty = True
            break

        before_halfway = GPIO.input(HALFWAY_TRIGGER) # True if trigger depressed.

    logging.debug("Rolling backward...")
    time.sleep(.1)
    if not tray_empty:
        slow_motor(pwm)
    while not before_halfway:
        pwm.ChangeDutyCycle(100)
        GPIO.output(MOTOR_FORWARD, False)
        GPIO.output(MOTOR_BACKWARD, True)

        before_halfway = GPIO.input(HALFWAY_TRIGGER) # True if trigger depressed.
    
    time.sleep(.1)
    if not tray_empty:
        take_in(pwm)

def slow_motor(pwm):
    """Slow down motor to make accept or reject decision."""
    logging.debug('Slowing motor.')
    pwm.ChangeDutyCycle(25)
    GPIO.output(MOTOR_FORWARD, False)
    GPIO.output(MOTOR_BACKWARD, True)
    # time.sleep(3)

    logging.info('Firing scanner for three seconds.')
    # call(["./scan", "3"])
    # scan = Popen(["./scan", "3"], stdout=PIPE)
    # output, err = p.communicate()
    barcode = subprocess.check_output(["./scan", "5"])

    if barcode:
        logging.info('Barcode read. Drawbridge down.')
        diverter.down()

        logging.info("Brocasting status - 'Accept.'")
        config.status = "accept"
        time.sleep(3) # allow time for accept message to play
    else:
        logging.info("Broacasting status - 'Reject.'")
        diverter.up()
        pwm.ChangeDutyCycle(100)
        time.sleep(1)
        pwm.ChangeDutyCycle(0)
        config.status = "reject"
        time.sleep(10) # allow time for reject message to play


def clean_up(pwm):
    """Roll backward to open tray, then shut down pins."""
    logging.info('Cleaning up.')
    pwm.ChangeDutyCycle(100)
    GPIO.output(MOTOR_FORWARD, False)
    GPIO.output(MOTOR_BACKWARD, True)
    time.sleep(1)

    pwm.stop()
    GPIO.cleanup()

def main():
    pwm = setup()
    take_in(pwm)
    clean_up(pwm)

if __name__ == '__main__':
    try:
        if os.geteuid() != 0:
            os.execvp("sudo", ["sudo"] + sys.argv)
        main()
    except KeyboardInterrupt:
        logging.info('Keyboard interrupt.')
        pwm = setup()
        clean_up(pwm)

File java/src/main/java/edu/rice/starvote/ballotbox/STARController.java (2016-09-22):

package edu.rice.starvote.ballotbox;

import auditorium.NetworkException;
import edu.rice.starvote.ballotbox.drivers.*;
import edu.rice.starvote.ballotbox.statusserver.StaticContainer;
import edu.rice.starvote.ballotbox.statusserver.StatusContainer;
import edu.rice.starvote.ballotbox.statusserver.StatusServer;
import edu.rice.starvote.ballotbox.util.GPIOListener;
import votebox.AuditoriumParams;

import java.util.Scanner;

/**
 * Main entry point of program. Instantiates all components of the ballot box software and links them together.
 *
 * @author luejerry
 */
public class STARController {

    private final GPIOListener listener;
    private final GPIOListener halfwaySensor;
    private final ISpooler spooler;
    private final IScanner scanner;
    private final IMotor motor;
    private final IDiverter diverter;
    private final IStatusUpdate updater;
    private final IValidator validator;
    private final Monitor monitor;
    private final StatusContainer statusProvider;
    private final StatusServer statusServer;


    /**
     * Instantiates all modules, performing the necessary linking. Does not start the paper listener or status server.
     *
     * @param serial Unique machine identifier number. Must correspond to a valid key in `/keys`.
     * @param launchCode Election day launch code, unique to each poll location.
     */
    public STARController(int serial, String launchCode) {
        listener = new GPIOListener(24);
        halfwaySensor = new GPIOListener(23);
        motor = new PrinterMotor(22, 27, new PWMBlaster(17, 50));
        diverter = new DiverterPWM(new PWMBlaster(18, 50));
        scanner = new Scan();

        STARConnector starConnector;
        IValidator tempValidator;
        try {
            starConnector = new STARConnector(serial, launchCode);
            final STARConnector star = starConnector;
            tempValidator = code -> {
                final BallotResult result = star.validate(code, 5000);
                return (result == BallotResult.ACCEPT);
            };
            System.out.println("Connected to the Auditorium network.");
        } catch (NetworkException e) {
            System.err.println("ERROR: Could not connect to the Auditorium network! Running in test mode only");
            e.printStackTrace();
            tempValidator = code -> true;
        }
        validator = tempValidator;

        statusProvider = StaticContainer.statusContainer;
        updater = status -> {
            System.out.println("Ballot status sent to server: " + status.toString());
            statusProvider.writeStatus(status);
        };
        spooler = new PaperSpooler(updater, diverter, motor, halfwaySensor, scanner, validator);
        monitor = new Monitor(listener, spooler);
        statusServer = new StatusServer(7654, statusProvider);
    }

    /**
     * Start the status server and paper listener. **This method does not return.**
     */
    public void run() {
        final Thread serverThread = new Thread(statusServer::start);
        serverThread.run();
        updater.pushStatus(BallotStatus.WAITING);
        monitor.run();
    }

    /**
     * Program main entry point. Starts up the ballot box.
     * @param args Ignored.
     */
    public static void main (String[] args) {
        final AuditoriumParams _constants = new AuditoriumParams("bs.conf");
        final int serial;
        if (args.length == 1) {
            serial = Integer.parseInt(args[0]);
        } else {
            serial = _constants.getDefaultSerialNumber();
        }
        if (serial == -1) {
            throw new RuntimeException("No machineID provided");
        }
        final Scanner keyboard = new Scanner(System.in);
        System.out.print("Enter launch code: ");
        final String launchCode = keyboard.next();
        keyboard.close();
        final STARController controller = new STARController(serial, launchCode);
        controller.run();
    }
}

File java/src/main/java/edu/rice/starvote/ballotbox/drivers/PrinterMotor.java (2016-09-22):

package edu.rice.starvote.ballotbox.drivers;

import com.pi4j.io.gpio.GpioPinDigitalOutput;
import com.pi4j.io.gpio.Pin;
import com.pi4j.io.gpio.PinState;
import edu.rice.starvote.ballotbox.util.GPIOManager;
import edu.rice.starvote.ballotbox.util.PinMap;

import java.io.IOException;

/**
 * Reference implementation of the feed motor controller, driving the main motor in an HP 1010 printer.
 *
 * @author luejerry
 */
public class PrinterMotor implements IMotor {

    private final GpioPinDigitalOutput forwardPin; // motor forward (pin 22)
    private final GpioPinDigitalOutput reversePin; // motor reverse (pin 27)
    private final IPWMDriver driver; // motor enable (pin 17)

    /**
     * Constructor.
     * @param forwardPin Pin that moves motor forward when HIGH (BCM numbering).
     * @param reversePin Pin that moves motor reverse when HIGH (BCM numbering).
     * @param driver PWM driver module.
     */
    public PrinterMotor(int forwardPin, int reversePin, IPWMDriver driver) {
        this.forwardPin = GPIOManager.controller().provisionDigitalOutputPin(PinMap.mapPin(forwardPin).get(), PinState.LOW);
        this.reversePin = GPIOManager.controller().provisionDigitalOutputPin(PinMap.mapPin(reversePin).get(), PinState.LOW);
        this.driver = driver;
    }

    /**
     * Constructor.
     * @param forwardPin Pin that moves motor forward when HIGH (Pi4J pin).
     * @param reversePin Pin that moves motor reverse when HIGH (Pi4J pin).
     * @param driver PWM driver module.
     */
    public PrinterMotor(Pin forwardPin, Pin reversePin, IPWMDriver driver) {
        this.forwardPin = GPIOManager.controller().provisionDigitalOutputPin(forwardPin, PinState.LOW);
        this.reversePin = GPIOManager.controller().provisionDigitalOutputPin(reversePin, PinState.LOW);
        this.driver = driver;
    }

    @Override
    public void stop() throws IOException {
        driver.setDutyCycle(0);
    }

    @Override
    public void forward() throws IOException {
        forwardPin.high();
        reversePin.low();
        driver.setDutyCycle(100);
    }

    @Override
    public void forwardSlow() throws IOException {
        forwardPin.high();
        reversePin.low();
        driver.setDutyCycle(25);
    }

    @Override
    public void forward(double speed) throws IOException {
        forwardPin.high();
        reversePin.low();
        driver.setDutyCycle(speed);
    }

    @Override
    public void reverse() throws IOException {
        reversePin.high();
        forwardPin.low();
        driver.setDutyCycle(100);
    }

    @Override
    public void reverseSlow() throws IOException {
        reversePin.high();
        forwardPin.low();
        driver.setDutyCycle(25);
    }

    @Override
    public void reverse(double speed) throws IOException {
        reversePin.high();
        forwardPin.low();
        driver.setDutyCycle(speed);
    }
}

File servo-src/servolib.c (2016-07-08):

/*
 * servolib
 *
 * Reimplementation of the servo library in C using wiringPi. This
 * approach uses the hardware PWM feature available on GPIO 18 of the
 * Raspberry Pi, reducing GPU usage and increasing timing accuracy over
 * the software based solution.
 *
 * Author:
 * Jerry Lue
 */
#include "servolib.h"

// #define PWM_PIN 18

void servo_init() {
	pinMode(PWM_PIN, PWM_OUTPUT);
	pwmSetMode(PWM_MODE_MS);
	pwmSetClock(375);
	pwmSetRange(1024);
}

void servo_move(int pos) {
	pwmWrite(PWM_PIN, pos);
}

/*
 * Move a HD 6001HB servo.
 *
 * For the 6001HB servo, raw input ranges from 40 (0.8 ms) to 120
 * (2.35 ms), which translates to a range of 0-80 for the input here.
 * Values outside this range may be used but response is not guaranteed.
 */
void hd6001_move(int pos) {
    servo_move(pos + 40);
}

/*
 * Move a Futaba S3003 servo.
 *
 * For the S3003 servo, raw input ranges from 20 (0.4 ms) to 120
 * (2.35 ms), which translates to a range of 0-100 for the input here.
 * Values outside this range may be used but response is not guaranteed.
 */
void s3003_move(int pos) {
    servo_move(pos + 20);
}

void servo_interactive() {
    while (1) {
        char input[6];
        int value;
        printf("Enter servo value (0-1024): ");
        fgets(input, 6, stdin);
        value = atoi(input);
        s3003_move(value);
    }
}

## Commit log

2016-05-27 Main execution.
    - call RPIO.cleanup() to reset every channel that has been set up by this
    program, and unexport interrupt gpio interfaces
    [take_in.py]
2016-05-27 Fix logic error.
    - HALFWAY_TRIGGER is an alias for pin 14.
    - after_halfway is a boolean that is True when the trigger is depressed.
    [take_in.py]
2016-05-30 Reverse for 1 second during cleanup.
    [take_in.py]
2016-06-02 added servo library, modified spooler pins
2016-06-07 Circuit diagram of current design
    [rpi-ballotbox.fzz]
2016-06-07 Update circuit diagram
    [rpi-ballotbox.fzz]
2016-06-07 Add code scanner controller to circuit diagram
    [rpi-ballotbox.fzz]
2016-06-07 Correct typo.
    - cleanup() --> clean_up()
    [take_in.py]
2016-06-07 Switch PWM pin: MOTOR_REVERSE -> MOTOR_ENABLE.
2016-06-08 Working implementation. Tested on Pi.
    - Create pwm objecti in setup() and pass it as an argument to every
    subsequent function.
2016-06-08 scan only outputs barcode to stdout, unless error
    [scan.c]
2016-06-10 Read code directly from scanner driver, and block its input from stdin
2016-06-21 add interactive servo testing program
2016-06-21 add diverter module, update servodriver comments to docstring, document interactive servo test module
2016-06-23 Barcode scanner mount schematic for 3d printing
    [holderbase.SLDPRT, holderbase.STL]
2016-06-24 Box enclosure solidworks schematics
    [ballotbox-assy.SLDASM, ballotbox-bottompart.sldprt, ballotbox-platepart.sldprt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]
2016-06-24 Moved solidworks files to box-schematics folder
    [holderbase.SLDPRT, holderbase.STL]
2016-06-24 Add documentation and PNG render of circuit diagram
    [rpi-ballotbox.fzz]
2016-06-24 Add 2d assembly drawings
    # Todo
    Convert to lasercutter illustrator files
    [ballotbox-assy.SLDASM, ballotbox-assy.SLDDRW]
2016-06-28 Fix orientation error on holder base part, in progress
    [holderbase.SLDDRW, holderbase.SLDPRT]
2016-06-28 Complete revision
    [holderbase.SLDPRT]
2016-06-28 begin implementing c servolib
2016-06-30 add makefile/header for c servolib
2016-06-30 move main out of servolib file
2016-06-30 implement c servo diverter program
2016-07-03 Update circuit diagram Add breadboard diagram Update readme
    [rpi-ballotbox.fzz]
2016-07-07 add diverter config to support both servos: edit diverter_config.py to set
2016-07-07 Capture votebox device state in the config.status
2016-07-08 Update barcode scanner mount to resolve scanning failure issues
    [holderbase.SLDPRT, holderbase.STL]
2016-07-08 Add render of updated barcode scanner mount
2016-07-09 Created PCB v1 layout
    [rpi-ballotbox.fzz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]
2016-07-10 Add power pads to pcb for future proofing
    [rpi-ballotbox.fzz]
2016-07-10 Fix PCB routing
    [rpi-ballotbox.fzz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]
2016-07-10 zip file of PCB gerber files
2016-07-10 Add IsoPro file for PCB prototyping
2016-07-11 Fix PCB routing issues
    [rpi-ballotbox.fzz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]
2016-07-11 Zip file for PCB
2016-07-11 Add audio amp circuit to diagram and PCB schematic
    [rpi-ballotbox.fzz]
2016-07-11 update pcb miller file
2016-07-12 Compact PCB schematic
    [rpi-ballotbox.fzz]
2016-07-12 Fix 3.5mm part in PCB schematic to reflect actual pinout
    [rpi-ballotbox.fzz]
2016-07-12 Broadcast current state of Votebox.
    - states: waiting, pending, accept, reject
2016-07-12 Complete board combine
    [rpi-ballotbox.fzz]
2016-07-13 Update PCB schematic, create new gerber files
    [rpi-ballotbox.fzz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]
2016-07-13 Zip new gerber files
2016-07-14 minor PCB routing optimizations
    [rpi-ballotbox.fzz]
2016-07-18 Increased audio chime volume, update PCB schematic
    [rpi-ballotbox.fzz]
2016-07-19 fix motor pin nums
    [take_in.py]
2016-07-19 Attempt fix socket not closing issue
    [votebox.py]
2016-07-19 fix malformed http response
    [config.py]
2016-07-19 tweak delay after ballot reject, lower feeder pwm frequency
2016-07-19 change pwm freq, adjust reject delay timing
2016-07-19 try fix socket not released issue
    [config.py]
2016-07-19 fix socket not releasing issue, adjust reject timing
    [config.py, take_in.py]
2016-07-27 Add mount board files for milling
    [mountboard.fzz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]
2016-07-29 Revision 3 of scanner holder: * Add clip mount for logic board * Reduce height * Add tab stop to constrain lateral movement
    [holderbase.SLDPRT, holderbase.STL, mountboard.fzz]
2016-07-29 Begin work on mounting plate for RPi
    [rpimount.DXF, rpimount.SLDDRW, rpimount.SLDPRT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]
2016-08-01 Create RPi mount contour for PCB router
    [rpimount.fzz]
2016-08-01 Add Gerber files for RPi mount CNC
    [rpimount_contour.gm1, rpimount_copperBottom.gbl, rpimount_copperTop.gtl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]
2016-08-02 Add RPi mount ISO file for CNC routing
2016-08-02 Fix incorrect path bug in Scan class, add diverter and motor tests
    [MotorTest.java]
2016-08-02 Fix improper paper feed timing
    [Monitor.java, PaperSpooler.java]
2016-08-02 More fixes to improper timing
    [PaperSpooler.java]
2016-08-02 Switch to pi-blaster to control motor speed
2016-08-02 Fix PWM with piblaster not working
    [PWMBlaster.java]
2016-08-02 Increase paper eject time to ensure full clearance
    [PaperSpooler.java]
2016-08-04 Major revision to PCB layout: change to single mount design
    [rpi-ballotbox.fzz]
2016-08-04 Fix minor issues with feeder not resetting after false detection, parallelize websocket status broadcast
    [Controller.java, PaperSpooler.java]
2016-08-11 Removed audio amp circuit from circuit diagram
    [rpi-ballotbox.fzz]
2016-08-12 Fix misaligned lateral tab stop on scan holder
    [holderbase.SLDPRT, holderbase.STL]
2016-08-12 Add PCB 2.0 gerber files for milling
    [rpi-ballotbox_PCB1_472410_contour.gm1, rpi-ballotbox_PCB1_472410_copperBottom.gbl, rpi-ballotbox_PCB1_472410_copperTop.gtl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]
2016-08-12 Add IsoPro file for PCB 2.0, unfinished
2016-08-16 Final isopro file for PCB milling
2016-08-17 PCB 2.01: adjust power jack position to align better with printer
    [rpi-ballotbox.fzz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]
2016-08-24 Switch to pi-blaster based servo controller, fix JAR resource loading issue
    [Controller.java, DiverterPython.java, PWMBlaster.java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]
2016-08-25 Make code print to console
2016-08-25 Reworked IO exception handling structure, added docummissing documentation, recompiled javadocs
    [Controller.java, DiverterPWM.java, DiverterPython.java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]
2016-09-01 Reorganized more things into packages, added javadoc package-infos, restructure event listeners in PaperSpooler to a more intuitive flow
2016-09-01 Removed undesired concurrency from paper monitor thread
2016-09-12 Move all ballot box files into ballotbox package, added javafx UI implementation (unfortunately does not work on ARM devices\!)
    [Controller.java, DiverterPWM.java, DiverterPython.java]
2016-09-21 Fix sound not playing to USB audio device on RPi
2016-09-21 Change sound mixer device to global singleton
2016-09-22 Add partial UI documentation, slow down feed motor
2016-09-23 Adjust feed motor speed
2016-09-27 Add variant of PCB using an IR reflective sensor instead of optointerrupter (only resistor values changed).
    [rpi-ballotbox-refl.fzz]
2016-09-28 Changed timing of status message display and paper feed, add some missing documentation
    [GPIOListener.java, Monitor.java, PaperSpooler.java]
2016-09-28 Update readme, update circuit diagram render
2016-09-28 Increase feed eject speed, add IR reflect sensor datasheet
2016-10-14 Revert "Add initial local multipage ballot functionality (untested)"
    This reverts commit db94be3a707e26bb2e4e7d1a7f900a063e4aec5f.
    [PaperSpooler.java]
2016-10-14 Fix bug with new GPIOListener not dealing with timeout correctly
    [GPIOListener.java]
2016-10-19 Reverse pin state detection for reflective IR sensor
    [Monitor.java]
